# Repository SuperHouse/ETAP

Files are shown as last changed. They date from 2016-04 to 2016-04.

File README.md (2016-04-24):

SuperHouse Automation Electronic Tap Controller
===============================================

Copyright 2015 SuperHouse Automation Pty Ltd  
SuperHouse site:  www.superhouse.tv  
SuperHouse email: info@superhouse.tv  

Arduino-compatible board designed to be a drop-in replacement for the
Ryemetal "Hotshot" electronic tap controller. Maintains the same physical
layout including position of LEDs and the main connector.

Features:

 * ATmega328P MCU
 * Arduino R3 headers
 * 5V and 3.3V voltage regulators
 * 3 x N-channel MOSFETs for controlling cold, warm, and hot water solenoids
 * 5 x status LEDs for cold, warm, hot, long, and short
 * Serial header in FTDI format

Oblique view

Top view

Bottom view

More information is available at:

  http://www.superhouse.tv/etap

INSTALLATION
------------
The design is saved as an EAGLE project. EAGLE PCB design software is
available from www.cadsoftusa.com free for non-commercial use. To use
this project download it and place the directory containing these files
into the "eagle" directory on your computer.

DISTRIBUTION
------------
The specific terms of distribution of this project are governed by the
license referenced below.

LICENSE
-------
Licensed under the TAPR Open Hardware License (www.tapr.org/OHL).
The "license" folder within this repository also contains a copy of
this license in plain text format.

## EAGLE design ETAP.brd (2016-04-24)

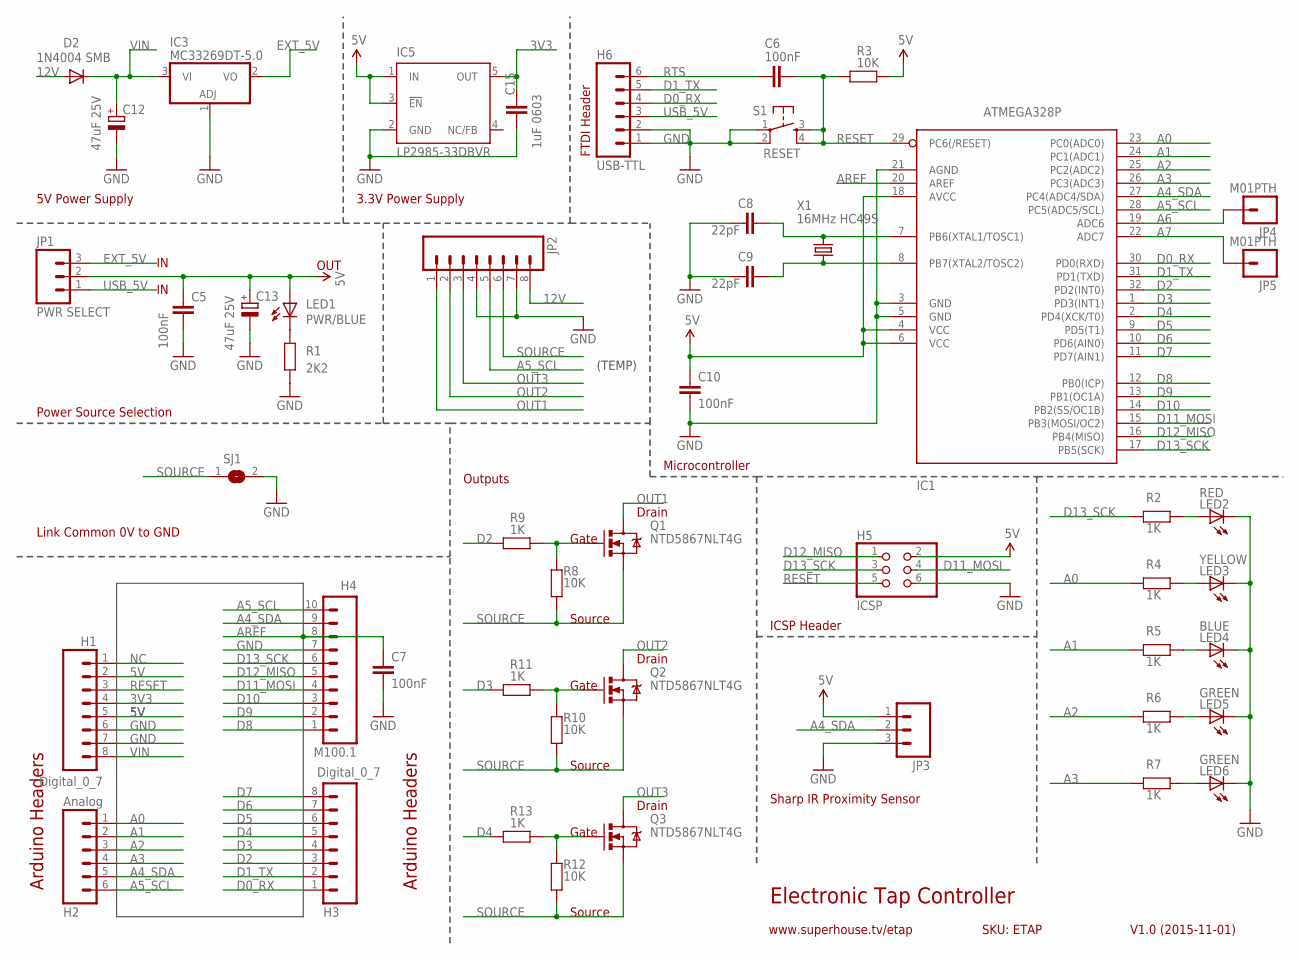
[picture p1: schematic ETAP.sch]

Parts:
C5, C6, C7, C10: 100nF; 0603
C8, C9: 22pF; 0603
C12, C13: 47uF 25V; PANASONIC_D
C15: 1uF 0603; 0603
D2: 1N4004 SMB; SMB-DIODE
H1, H3: Digital_0_7; 1X08
H2: Analog; 1X06
H4: M100.1; 1X10
H5: ICSP; 2X03
H6: USB-TTL; 1X06
IC1: ATMEGA328P; TQFP32-08
IC3: MC33269DT-5.0; DPACK
IC5: LP2985-33DBVR; TEXAS_SOT23-DBV
JP1: PWR SELECT; 1X03
JP2: M08STD; 1X08
JP3: M03PTH; 1X03
JP4, JP5: M01PTH; 1X01
LED1: PWR/BLUE; LED-0603
LED2: RED; LED3MM
LED3: YELLOW; LED3MM
LED4: BLUE; LED3MM
LED5, LED6: GREEN; LED3MM
Q1, Q2, Q3: NTD5867NLT4G; DPACK
R1: 2K2; 0603
R2, R4, R5, R6, R7, R9, R11, R13: 1K; 0603
R3, R8, R10, R12: 10K; 0603
S1: RESET; TACTILE-PTH
SJ1: SJ
X1: 16MHz HC49S; HC49U-V

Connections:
3V3: C15.2, H1.4, IC5.5 (OUT)
5V: C5.1, C10.1, C13.+, H1.2, H1.5, H5.2, IC1.4 (VCC), IC1.6 (VCC), IC1.18 (AVCC), IC5.1 (IN), IC5.3 (!EN), JP1.2, JP3.1, LED1.A, R3.2
12V: D2.A, JP2.8
A0: H2.1, IC1.23 (PC0(ADC0)), R4.2
A1: H2.2, IC1.24 (PC1(ADC1)), R5.2
A2: H2.3, IC1.25 (PC2(ADC2)), R6.2
A3: H2.4, IC1.26 (PC3(ADC3)), R7.2
A4_SDA: H2.5, H4.9, IC1.27 (PC4(ADC4/SDA)), JP3.2
A5_SCL: H2.6, H4.10, IC1.28 (PC5(ADC5/SCL)), JP2.5
A6: IC1.19 (ADC6), JP4.1
A7: IC1.22 (ADC7), JP5.1
AREF: C7.1, H4.8, IC1.20 (AREF)
D0_RX: H3.1, H6.4, IC1.30 (PD0(RXD))
D1_TX: H3.2, H6.5, IC1.31 (PD1(TXD))
D2: H3.3, IC1.32 (PD2(INT0)), R9.2
D3: H3.4, IC1.1 (PD3(INT1)), R11.2
D4: H3.5, IC1.2 (PD4(XCK/T0)), R13.2
D5: H3.6, IC1.9 (PD5(T1))
D6: H3.7, IC1.10 (PD6(AIN0))
D7: H3.8, IC1.11 (PD7(AIN1))
D8: H4.1, IC1.12 (PB0(ICP))
D9: H4.2, IC1.13 (PB1(OC1A))
D10: H4.3, IC1.14 (PB2(SS/OC1B))
D11_MOSI: H4.4, H5.4, IC1.15 (PB3(MOSI/OC2))
D12_MISO: H4.5, H5.1, IC1.16 (PB4(MISO))
D13_SCK: H4.6, H5.3, IC1.17 (PB5(SCK)), R2.2
EXT_5V: IC3.2 (VO), JP1.3
GND: C5.2, C7.2, C8.1, C9.1, C10.2, C12.-, C13.-, C15.1, H1.6, H1.7, H4.7, H5.6, H6.1, H6.2, IC1.3 (GND), IC1.5 (GND), IC1.21 (AGND), IC3.1 (ADJ), IC5.2 (GND), JP2.4, JP2.7, JP3.3, LED2.K (C), LED3.K (C), LED4.K (C), LED5.K (C), LED6.K (C), R1.1, S1.1, S1.2, SJ1.2
unnamed: Q2.1 (G), R10.2, R11.1
unnamed: LED2.A, R2.1
unnamed: Q1.1 (G), R8.2, R9.1
unnamed: Q3.1 (G), R12.2, R13.1
unnamed: C8.2, IC1.7 (PB6(XTAL1/TOSC1)), X1.2
unnamed: C9.2, IC1.8 (PB7(XTAL2/TOSC2)), X1.1
unnamed: LED3.A, R4.1
unnamed: LED4.A, R5.1
unnamed: LED5.A, R6.1
unnamed: LED6.A, R7.1
unnamed: LED1.C, R1.2
NC: H1.1
OUT1: JP2.1, Q1.2 (D)
OUT2: JP2.2, Q2.2 (D)
OUT3: JP2.3, Q3.2 (D)
RESET: C6.2, H1.3, H5.5, IC1.29 (PC6(/RESET)), R3.1, S1.3, S1.4
RTS: C6.1, H6.6
SOURCE: JP2.6, Q1.3 (S), Q2.3 (S), Q3.3 (S), R8.1, R10.1, R12.1, SJ1.1
USB_5V: H6.3, JP1.1
VIN: C12.+, D2.C, H1.8, IC3.3 (VI)

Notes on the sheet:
Electronic Tap Controller
V1.0 (2015-11-01)
SKU: ETAP
www.superhouse.tv/etap
5V Power Supply
Power Source Selection
Arduino Headers
ICSP Header
Microcontroller
OUT
FTDI Header
Drain
Gate
Source
Sharp IR Proximity Sensor
3.3V Power Supply
Link Common 0V to GND
Outputs
(TEMP)

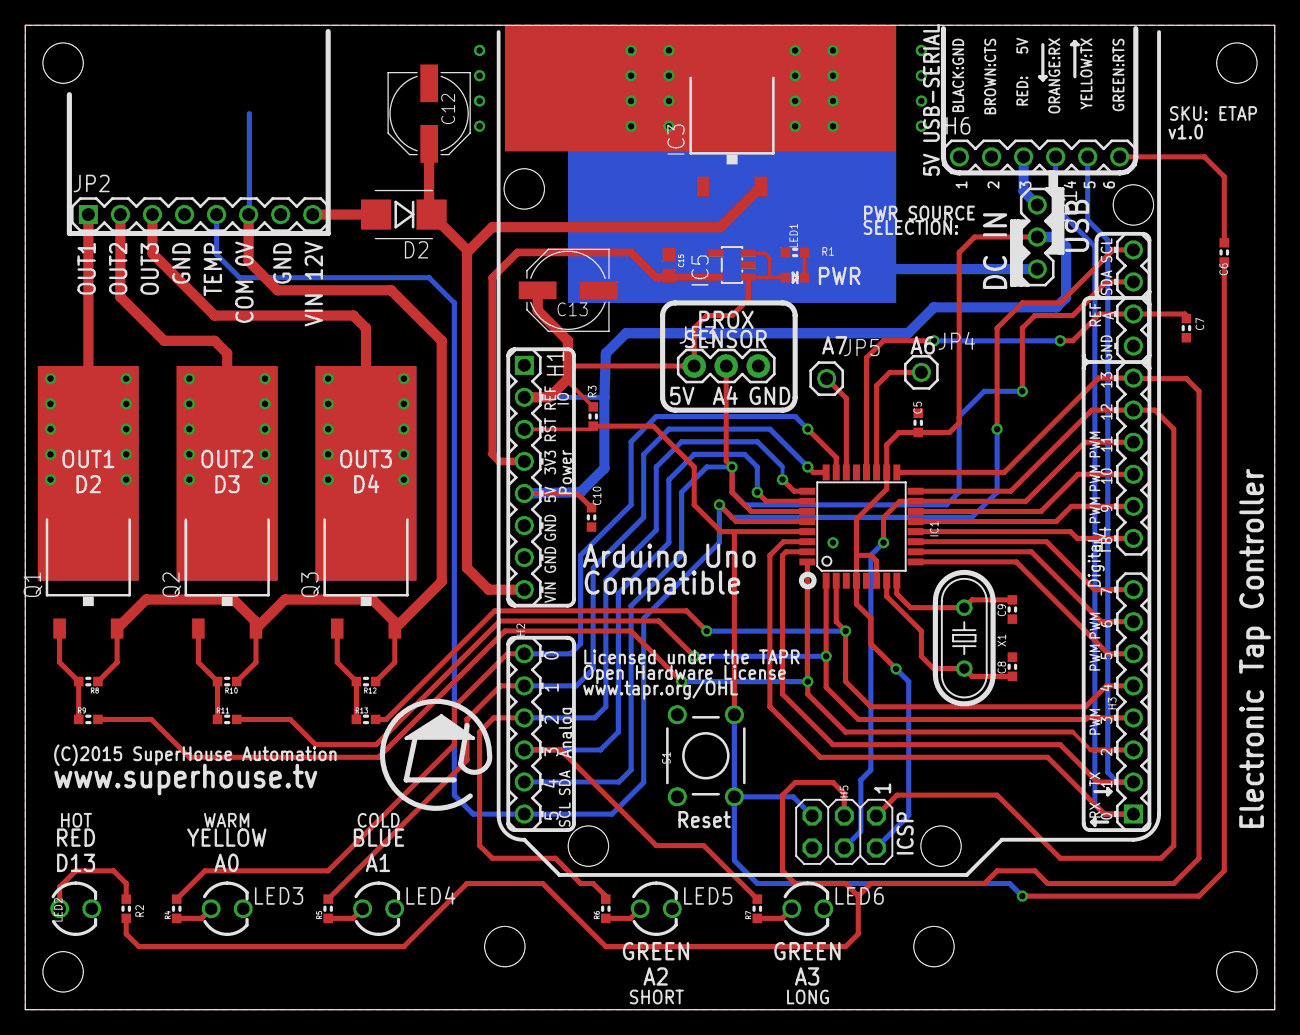
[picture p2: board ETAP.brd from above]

Board: 2 copper layers, 99.0 x 78.0 mm, 49 parts (1 on the bottom side), 47 nets.

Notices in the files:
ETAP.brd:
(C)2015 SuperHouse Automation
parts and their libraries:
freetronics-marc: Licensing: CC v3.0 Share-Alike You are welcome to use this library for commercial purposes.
